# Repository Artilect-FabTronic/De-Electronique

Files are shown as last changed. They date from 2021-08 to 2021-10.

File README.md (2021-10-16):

# Projet de dé électronique

L'ambition de ce projet, est de vous permettre de vous initier à la conception d'une carte électronique à travers un exemple simple, que vous concevrez vous même.
Une fois que vous s'aurez dessiner et réaliser un premier circuit imprimer (PCB), vous pourrez réaliser vos propres montages électroniques.

## Description

On se propose de réaliser le dé électronique d'Heliox, qui lorsqu'on le secoue, tire un numéro de 1 à 6 de manière aléatoire.

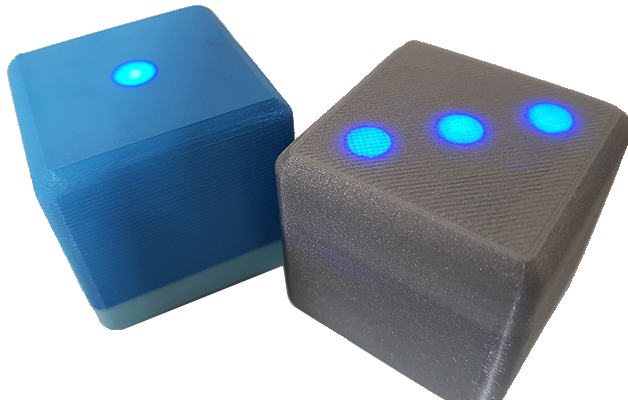
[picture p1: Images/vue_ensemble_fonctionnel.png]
Dé réalisé par Heliox


L'objectif est d'avoir un système minimaliste afin de pouvoir le faire fonctionner à partir d'une pile bouton de 3V.

Nous utiliserons donc un microcontrôleur ATtiny85 du fabricant Microchip, compatible avec les cartes Arduino ([ATtiny microcontroller comparison chart](https://en.wikipedia.org/wiki/ATtiny_microcontroller_comparison_chart)).

Voici deux sources du projet, parmi d'autres que vous retrouverez sur Internet.

1. <http://carrefour-numerique.cite-sciences.fr/wiki/doku.php?id=projets:de_electronique>

2. Le tutoriel d'Heliox est articulé en 4 épisodes :
    1. 📺 [Fabrication d'un circuit imprimé avec transfert de toner](https://youtu.be/8joLK039fjk)
    2. 📺 [Explication rapide du circuit imprimé et comment placer les composants dessus](https://youtu.be/6BOH1eVT2Hk)
    3. 📺 [Programmation du microcontrôleur ATtiny85 pour faire fonctionner le dé](https://youtu.be/S-oBujsoe-Q), [Code source HelioxLab](https://github.com/HelioxLab/electronicdice)
    4. 📺 [Création et modélisation de l'objet 3D final](https://youtu.be/o8AYCznNaCQ)

<!-- Routage du PCB réalisé par Heliox avec le logiciel  <https://fritzing.org/download/> -->
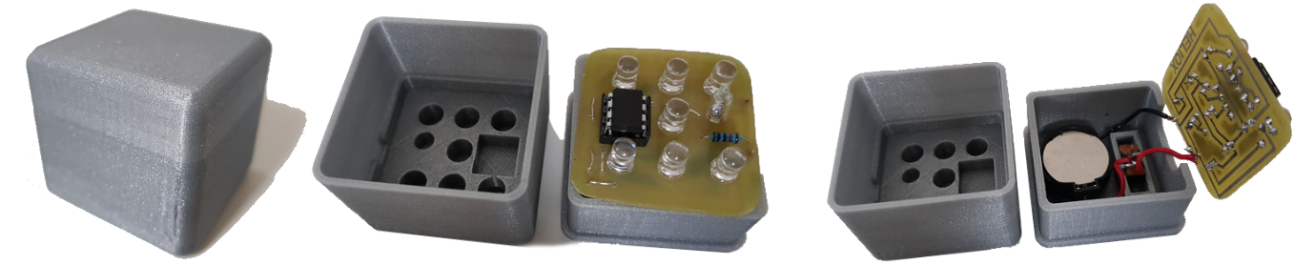
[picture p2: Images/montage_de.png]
montage du de conçu par Heliox


## Evolution possible du projet

- Projet initial à partir du tutoriel d'Heliox et des composants traversants
- Même projet mais avec une carte électronique supportant des composants CMS
- Autre version avec l'utilisation de [registre à décalage](https://fr.wikipedia.org/wiki/Registre_%C3%A0_d%C3%A9calage) pour le pilotage des LED
- [Projet plus ambitieux avec des LED sur toutes les faces](https://www.youtube.com/watch?v=6NPTslF68Q0&ab_channel=maker.moekoe)

## Les outils logiciels utilisés

- CAO éléctronique KiCad en version 5.99 "[Nightly Development Builds](https://www.kicad.org/download/windows/)", est téléchargeable depuis la page du serveur, aller tout en bas pour trouver la dernière date de compilation :
<https://kicad-downloads.s3.cern.ch/index.html?prefix=windows/nightly/>
- CAO mécanique [FreeCAD](https://www.freecadweb.org/?lang=fr)
- [Arduino IDE 1.8.15](https://www.arduino.cc/en/software)
- [Visual Studio Code](https://code.visualstudio.com/)

## Le matériel du projet dé électronique (BOM)

- Matériaux PLA pour l'imprimante 3D, à partir des [fichiers STL fournis par HELIOX](https://www.thingiverse.com/thing:2798081)
- Un fer à souder pour assembler les composants sur le circuit imprimé (PCB), ainsi qu'un petit outillage, comme un multimètre, des pinces, etc...
- [Interrupteur à bascule 3 broches 1P2T, poignée haute 4 mm, SS12F15](https://fr.aliexpress.com/item/32765155281.html)
- [Piles bouton au Lithium 3V, CR2032](https://fr.aliexpress.com/item/1005001314447472.html)
- [ATtiny85](https://www.microchip.com/wwwproducts/en/ATtiny85), [Microcontrôleur MCU 8BIT 20MHZ, 8 broches DIP-8 ATTINY85](https://fr.aliexpress.com/item/32952262601.html), [ATTINY85V-10PU](https://octopart.com/attiny85v-10pu-microchip-77762335), [Farnell 1455165](https://fr.farnell.com/microchip/attiny85v-10pu/mcu-8bit-attiny-10mhz-dip-8/dp/1455165) (l'option V permet de descendre la tension d'alimentation jusqu'à 1V8)
- Interrupteur à bille (mouvement et inclinaison) : [Capteur de vibrations en métal, Boule d'inclinaison secouant commutateur, SW-520D SW520D](https://www.aliexpress.com/item/100PCS-SW-520D-SW520D-Vibration-Sensor-Metal-Ball-Tilt-Shaking-Switch/4000680935322.html)
- [Kit de LED, taille 5 mm, 2V ou 3 V, ensemble d'ampoules couleurs chaudes, blanc, rouge, bleu, vert, orange, jaune](https://fr.aliexpress.com/item/1936218827.html)
- [Assortiment de condensateurs électrolytiques, 125 Pieces 1uF 2200uF 25 Valeurs](https://www.amazon.fr/gp/product/B00JZETYIG/ref=ppx_yo_dt_b_asin_title_o01_s00)
- [Boîtier/Socket support DIP 8 broches, 0.3 inch / 7.62mm](https://www.amazon.fr/gp/product/B016S6ZQQM/ref=ppx_yo_dt_b_asin_title_o00_s00)
- [Kit résistance à fil métallique, 600 pcs/lot, 30 valeurs* 20 pcs de 10 ohms ~ 1 M ohm, 1 %, 1/4 W](https://fr.aliexpress.com/item/1005001774876666.html)
- [Support de piles, CR2032, pour piles bouton 3V](https://fr.aliexpress.com/item/32845557622.html),  modèle 3D : [20mm THT Coin Cell Holder](https://grabcad.com/library/20mm-tht-coin-cell-holder-1)

---

## Schématique

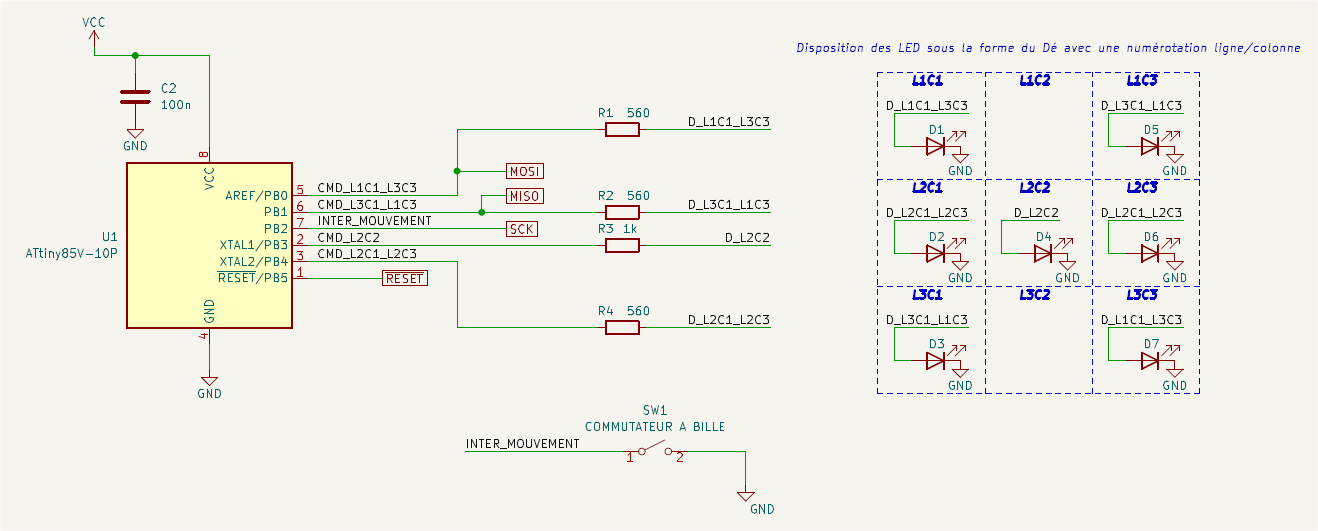
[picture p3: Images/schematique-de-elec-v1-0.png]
schematique-de-elec-v1-0


"arduino attiny85 pinout" depuis la page : https://learn.sparkfun.com/tutorials/tiny-avr-programmer-hookup-guide/attiny85-use-hints

Brochage (Pinout en Anglais) de l'ATtiny85 :

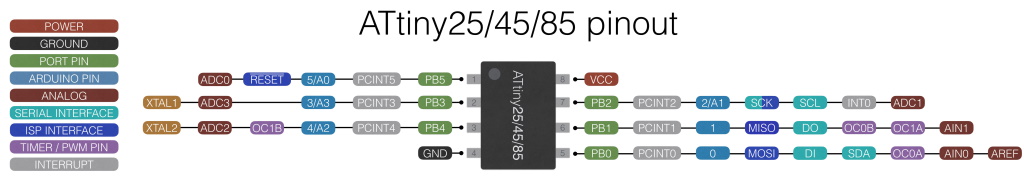
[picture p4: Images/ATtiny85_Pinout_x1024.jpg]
ATtiny85 Pinout


[Programmation de l’ATtiny85](http://makerspace56.org/transformer-une-arduino-uno-en-programmateur-isp-dattiny-par-exemple/)

Afin de pouvoir programmer l'ATtiny85, nous utiliserons un connecteur dit **_ISP_** ou **_ICSP_** pour In-circuit Serial Programmer, de 2x3 broches, voir [Arduino as ISP and Arduino Bootloaders](https://www.arduino.cc/en/pmwiki.php?n=Tutorial/ArduinoISP).

Nous pouvons nous inspirer du schéma d'implantation du connecteur de programmation ICSP à partir du schéma de la [carte Arduino Nano](https://store.arduino.cc/arduino-nano).

Et pour la programmation, suivre les instruction ici : [Programming ATtiny85 with Arduino Uno](https://create.arduino.cc/projecthub/arjun/programming-attiny85-with-arduino-uno-afb829)

Si vous avez tous suivi, vous aurez vu que par défaut, l'environnement Arduino IDE ne prend pas en charge les microcontrôleurs ATtiny85. Nous devons donc ajouter les cartes ATtiny à l'IDE Arduino.

Pour cela, ouvrez le menu "Fichier -> Préférences" et dans les URL du gestionnaire de cartes supplémentaires, ajoutez cette URL :

`https://raw.githubusercontent.com/damellis/attiny/ide-1.6.x-boards-manager/package_damellis_attiny_index.json`

Puis ajouter le support pour les [ATtiny](https://github.com/damellis/attiny) depuis le gestionnaire de carte.

Une fois cela effectué, vous pourrez choisir le type de carte ATtiny25/45/85, préciser bien le modèle du "processeur" ATtiny85 et le choix de l'horloge interne à 8 MHz.

TODO: passer à 1 MHz et voir la différence de consommation...

## Carte électronique

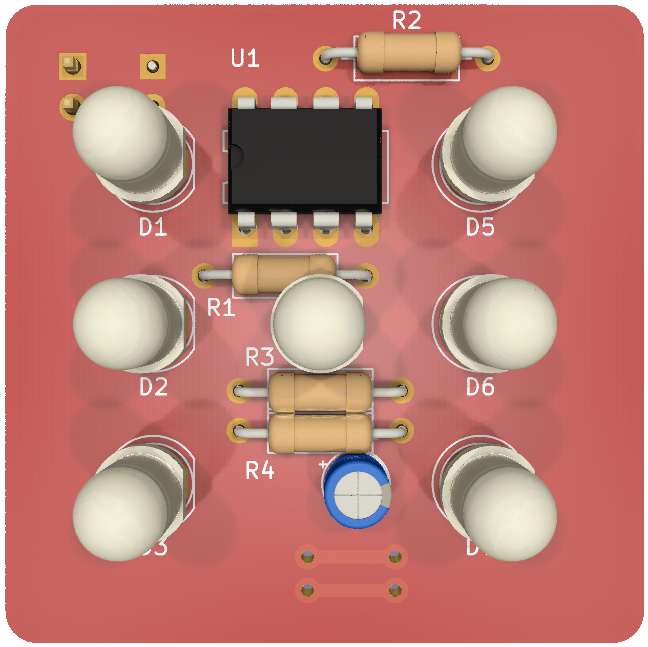
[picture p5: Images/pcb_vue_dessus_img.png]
carte-de-elec-v1-0-vue-dessus
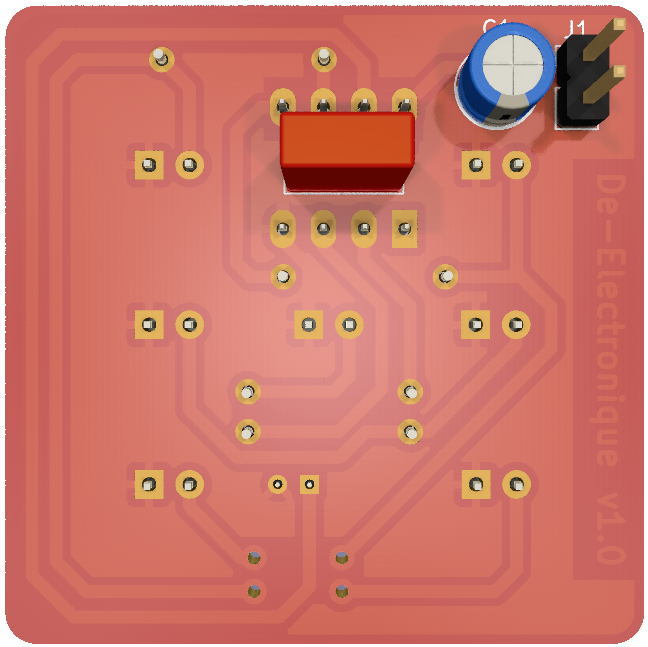
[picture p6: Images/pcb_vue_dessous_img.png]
carte-de-elec-v1-0-vue-dessous


### Programmation de l'ATtiny85 depuis une carte Arduino Uno

Une fois le programme compilé sous l'IDE Arduino (version 1.8.16 sous Windows 10, avec les paramètres de carte : "ATtiny25/45/85, ATtiny85, Internal 8 MHz"), il est important pour la programmation de votre ATtiny85 cible de bien configurer le programmer externe, afin de pouvoir effectuer la programmation.

---

### Description du fonctionnement

Nous allons étudier ensemble le montage électronique ;-)

Le microcontrôleur ATtiny85 dispose de 8 broches, dont 2 sont réservées pour son alimentation électrique.

Nous devons donc sélectionner les broches numériques d'entrées/sorties (E/S) permettant le bon fonctionnement de notre projet.

Tout d'abord, nous aurons besoin d'une entrée pour le capteur de mouvement à bille.
Il faut alors ce pencher sur les fonctions des broches du microcontrôleur afin de pouvoir décider quelle broche nous sera utile afin de pouvoir détecter cet évènement.

Mettre les LED sous la forme du dé avec une numérotation Ligne/Colonne (L/C) :

| L/C  |  C1  |  C2  |  C3  |
|:---:|:----:|:----:|:----:|
| **L1** | L1C1 | L1C2 | L1C3 |
| **L2** | L2C1 | L2C2 | L2C3 |
| **L3** | L3C1 | L3C2 | L3C3 |

- Chiffre 1 : (L2C2)
- Chiffre 2 : (L3C1 + L1C3)
- Chiffre 3 : (L3C1 + L1C3) + (L2C2)
- Chiffre 4 : (L3C1 + L1C3) + (L1C1 + L3C3)
- Chiffre 5 : (L3C1 + L1C3) + (L1C1 + L3C3) + (L2C2)
- Chiffre 6 : (L3C1 + L1C3) + (L1C1 + L3C3) + (L2C1 + L2C3)

En regroupant les LED entre parenthèse, nous voyant que nous devons piloter séparément les groupes suivant, si l'on veux pouvoir afficher tous les chiffres :

- 1 broche en sortie pour commander la LED L2C2, nous la nommerons CMD_L2C2
- 1 broche en sortie pour commander les LED L3C1 et L1C3, nous la nommerons CMD_L3C1L1C3
- 1 broche en sortie pour commander les LED L1C1 et L3C3, nous la nommerons CMD_L1C1L3C3
- 1 broche en sortie pour commander les LED L2C1 et L2C3, nous la nommerons CMD_L2C1C3

Soit un total de 4 broches en sorties pour la commande des LED du projet :

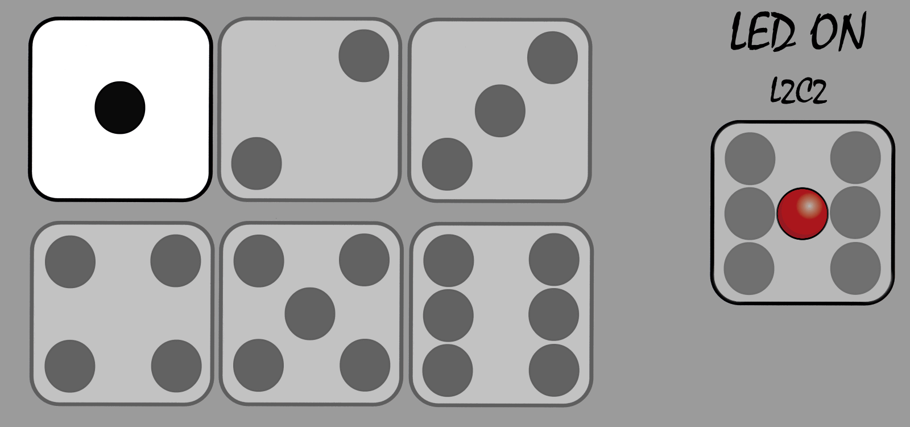
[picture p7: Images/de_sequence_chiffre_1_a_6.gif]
Pilotage des LED


Consommation en veille = 373 uA
Consommation au repos = 800 uA
Consommation avec 1 LED = 2.62 mA
Consommation avec 4 LED = 8.13 mA

---

## Internet ⚀, ⚁, ⚂, ⚃, ⚄, ⚅

- [Dé — Wikipédia](https://fr.wikipedia.org/wiki/D%C3%A9)
- [Lancez un dé virtuel!](https://de.virtuworld.net/)
- [Patrons de dés à jouer](https://www.fiche-maternelle.com/fabriquer-son-des-a-jouer.html)
- [Fabriquer soit même un Dé électronique sans Arduino](https://www.youtube.com/watch?v=spbdDq6kvxw&ab_channel=ElectroMic)
- [dé électronique qui se déclenche par passage de la main au dessus d'une photorésistance](https://sciences-du-numerique.fr/projet-arduino-pour-la-specialite-isn/de-electronique/41)

---

## License

MIT License Projet Open Hardware et Open Source by Artilect (https://opensource.org/licenses/MIT)

[Open Hardware](https://fr.wikipedia.org/wiki/Mat%C3%A9riel_libre)

[MIT License](https://opensource.org/licenses/MIT)

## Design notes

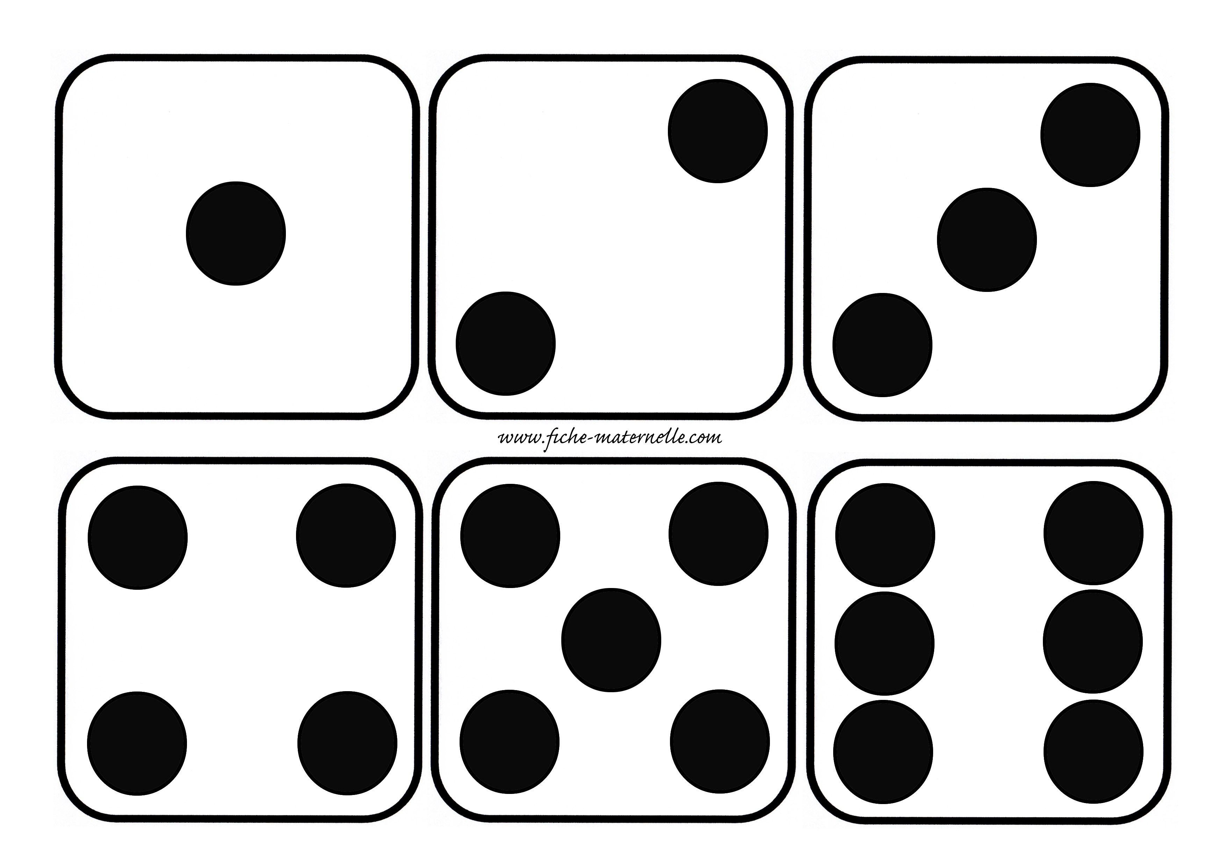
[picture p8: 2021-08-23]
Images/les_faces_du_de.jpg

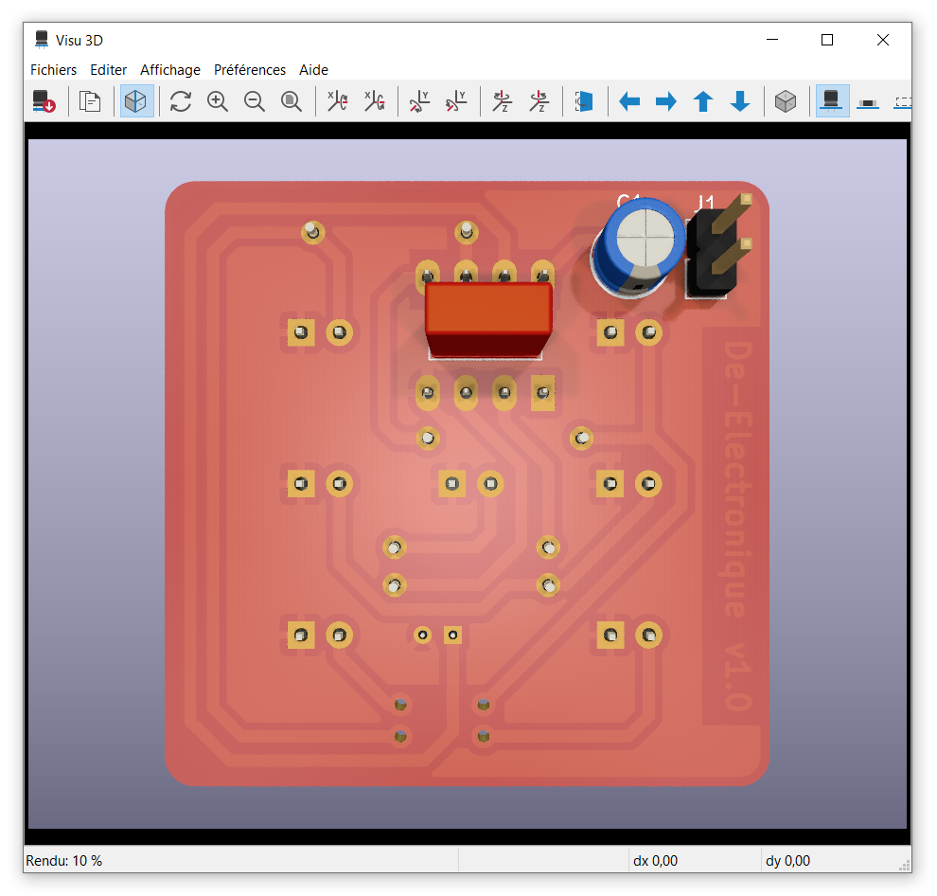
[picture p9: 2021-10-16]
Images/pcb_vue_dessous.png

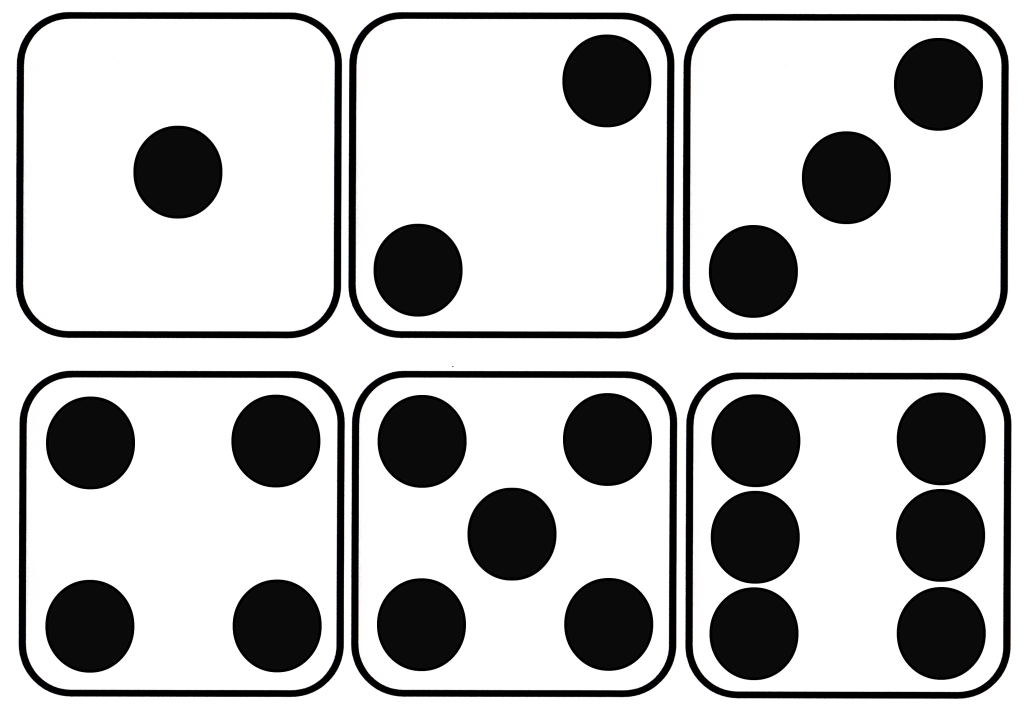
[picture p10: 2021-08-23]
Images/les_faces_du_de.png

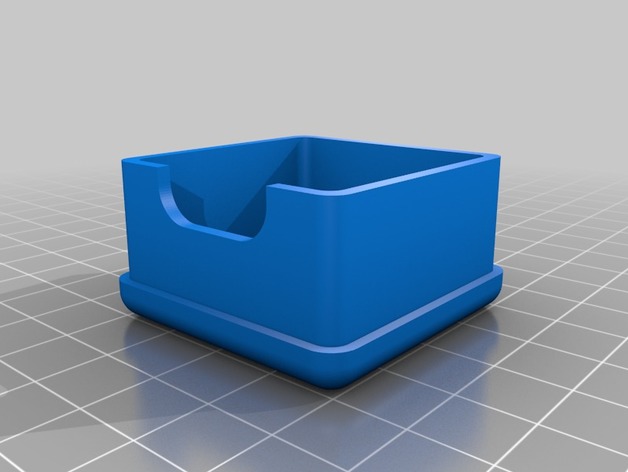
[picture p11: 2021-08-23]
Images/vue_dessous.jpg

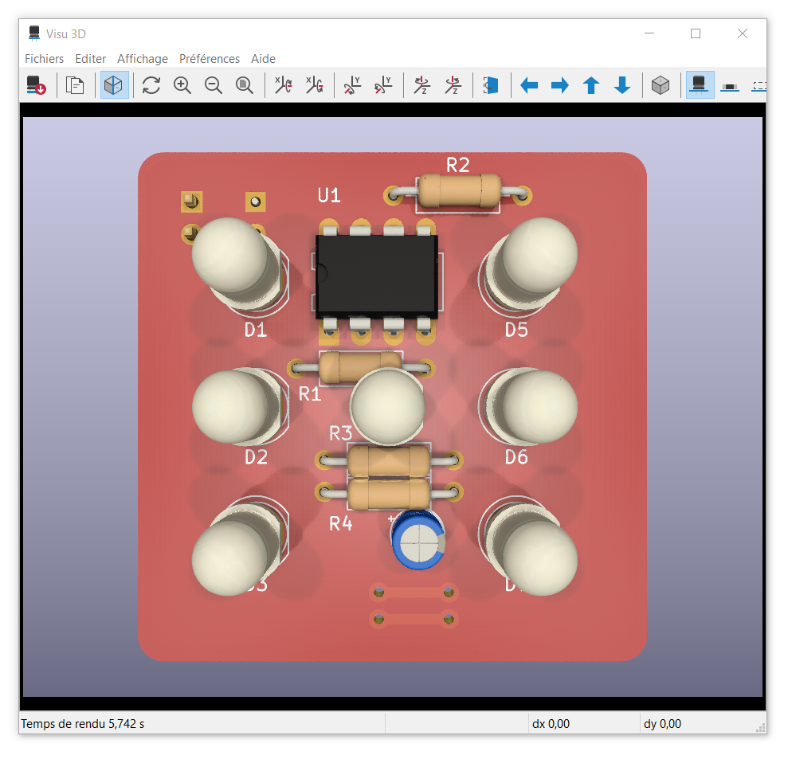
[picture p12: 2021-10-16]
Images/pcb_vue_dessus.png

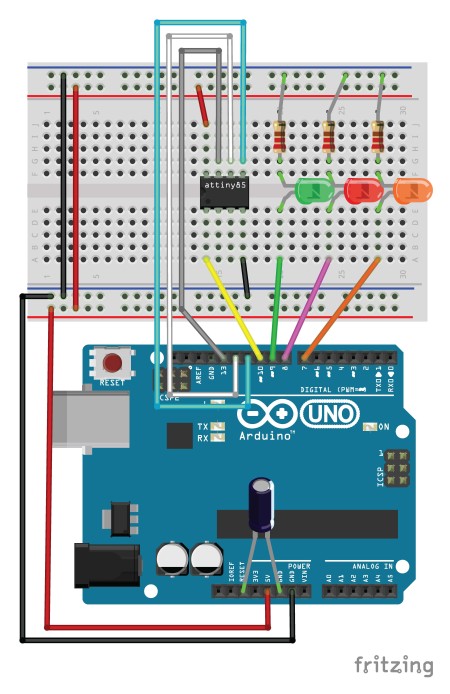
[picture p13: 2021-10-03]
Images/Programmation-AtTiny85-ArduinoUno-ISP.jpg

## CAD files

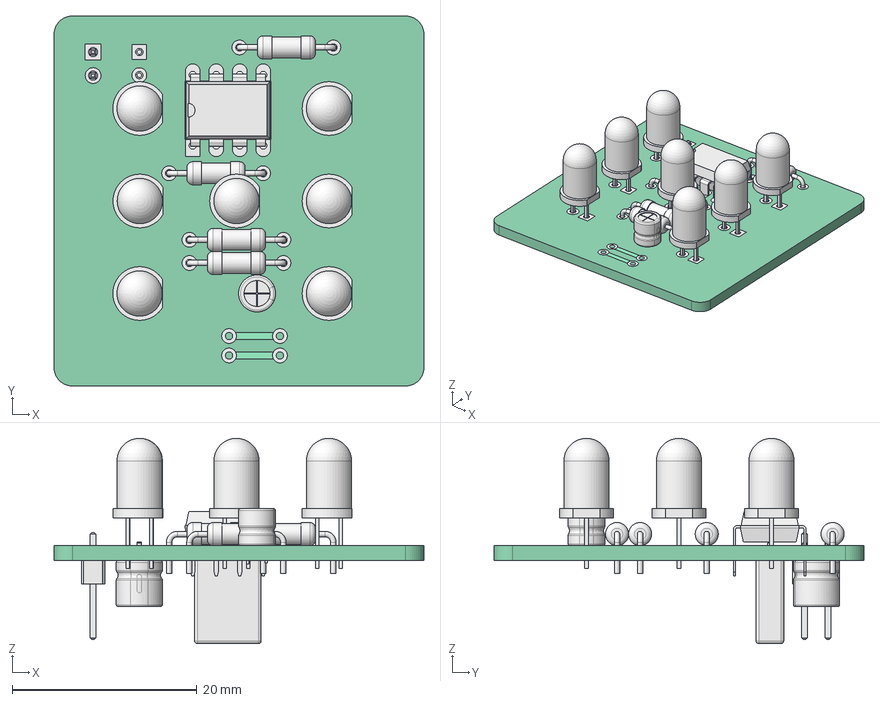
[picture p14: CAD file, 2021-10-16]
CAO-3D/PCB-De-Elec-THT.FCStd
40.0 x 40.0 x 22.2 mm
Pcb_6ee0
topPads_6ee0
topTracks_6ee0
botPads_6ee0
botTracks_6ee0
botZones_6ee0
D3_LED_D5.0mm_Clear_c8d51a1c0c0e x 7
U1_DIP-8_W7.62mm_69495754b2d9
R3_R_Axial_DIN0207_L63mm_D25mm_P1016mm_Horizontal_48222e3e548a x 4
SW1_CP_Radial_D40mm_P200mm_0d74ae5376be
C2_C_Rect_L72mm_W30mm_P500mm_FKS2_FKP2_MKS2_MKP2_9a8d65592bbd
J1_PinHeader_1x02_P254mm_Vertical_77a5e3965d3b
C1_CP_Radial_D50mm_P250mm_6f870ca8c2a1

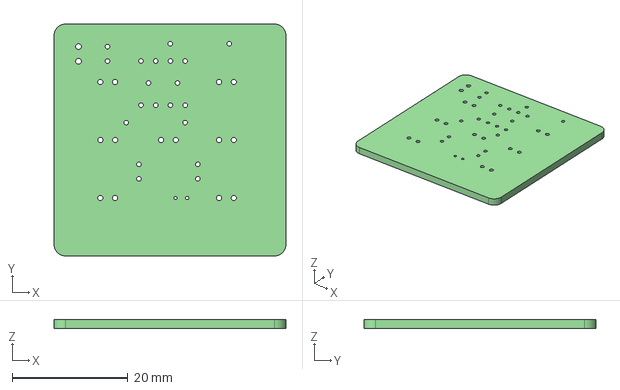
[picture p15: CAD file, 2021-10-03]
CAO-Kicad/CAO-Kicad.step
40.0 x 40.0 x 1.60 mm

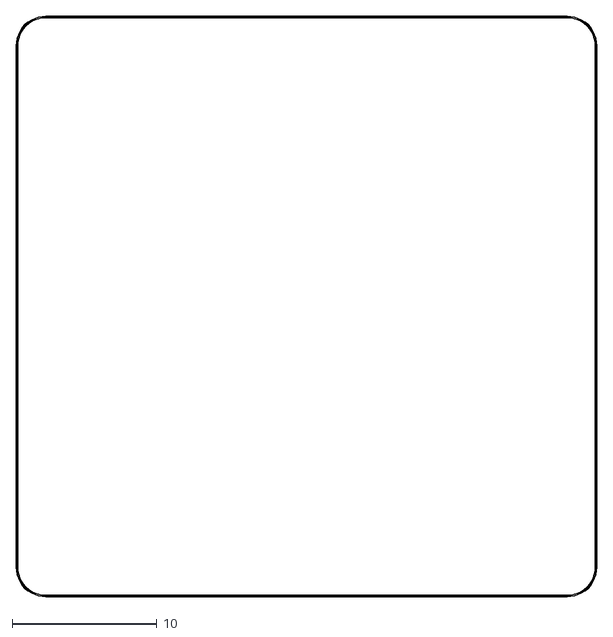
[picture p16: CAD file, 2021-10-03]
CAO-Kicad/GERBER/CAO-Kicad-Edge_Cuts.dxf
40.1 x 40.1

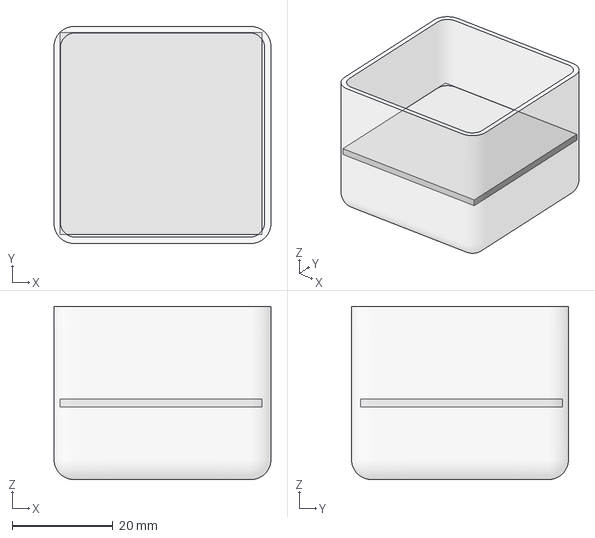
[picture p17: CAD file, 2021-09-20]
CAO-3D/Top-To-PCB.FCStd
43.0 x 43.0 x 34.3 mm
PCB
Top

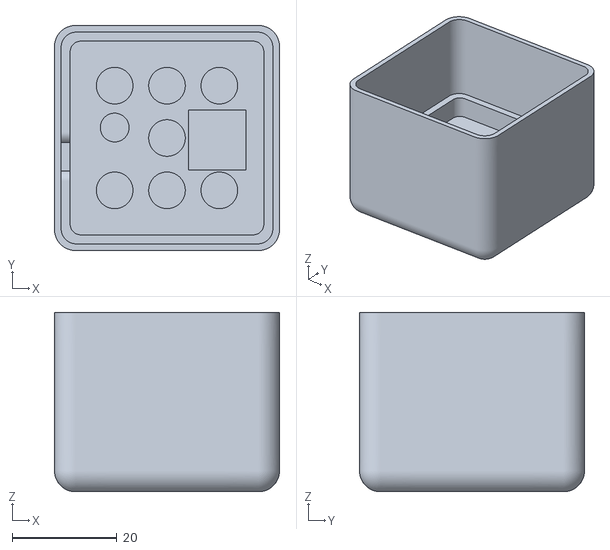
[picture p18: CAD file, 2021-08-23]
CAO-3D/Top.stl
43.0 x 43.0 x 34.3

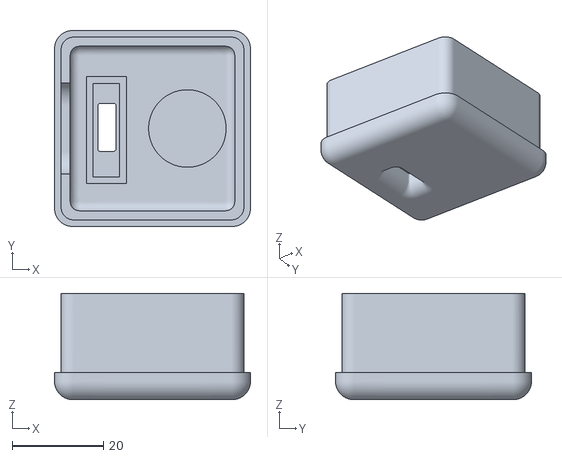
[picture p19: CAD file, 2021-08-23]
CAO-3D/Bottom.stl
43.0 x 43.0 x 23.3

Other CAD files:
CAO-Kicad/GERBER/CAO-Kicad-B_Silkscreen.dxf
CAO-Kicad/GERBER/CAO-Kicad-F_Silkscreen.dxf

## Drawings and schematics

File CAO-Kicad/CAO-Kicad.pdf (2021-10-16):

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

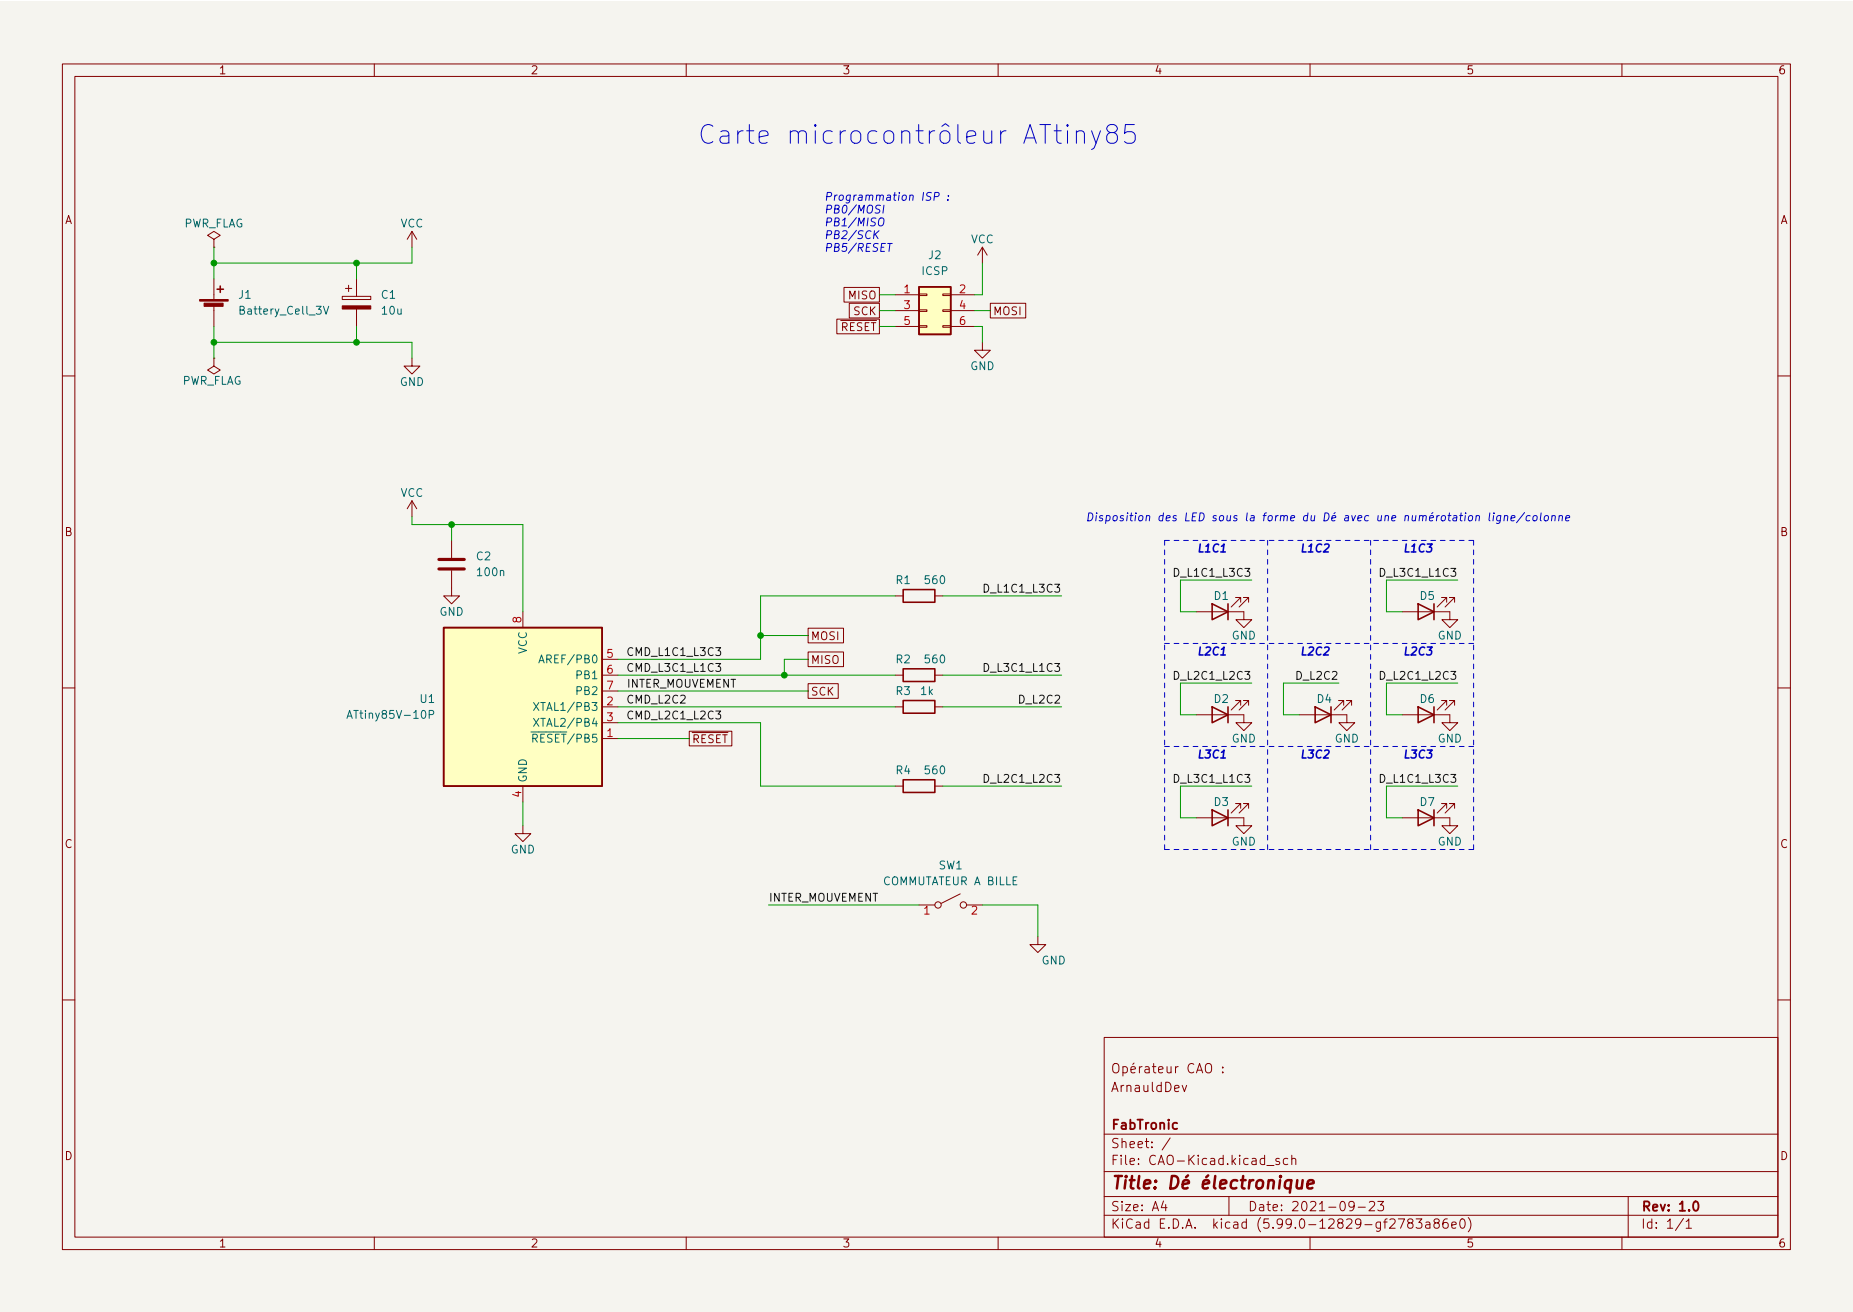
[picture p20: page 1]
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

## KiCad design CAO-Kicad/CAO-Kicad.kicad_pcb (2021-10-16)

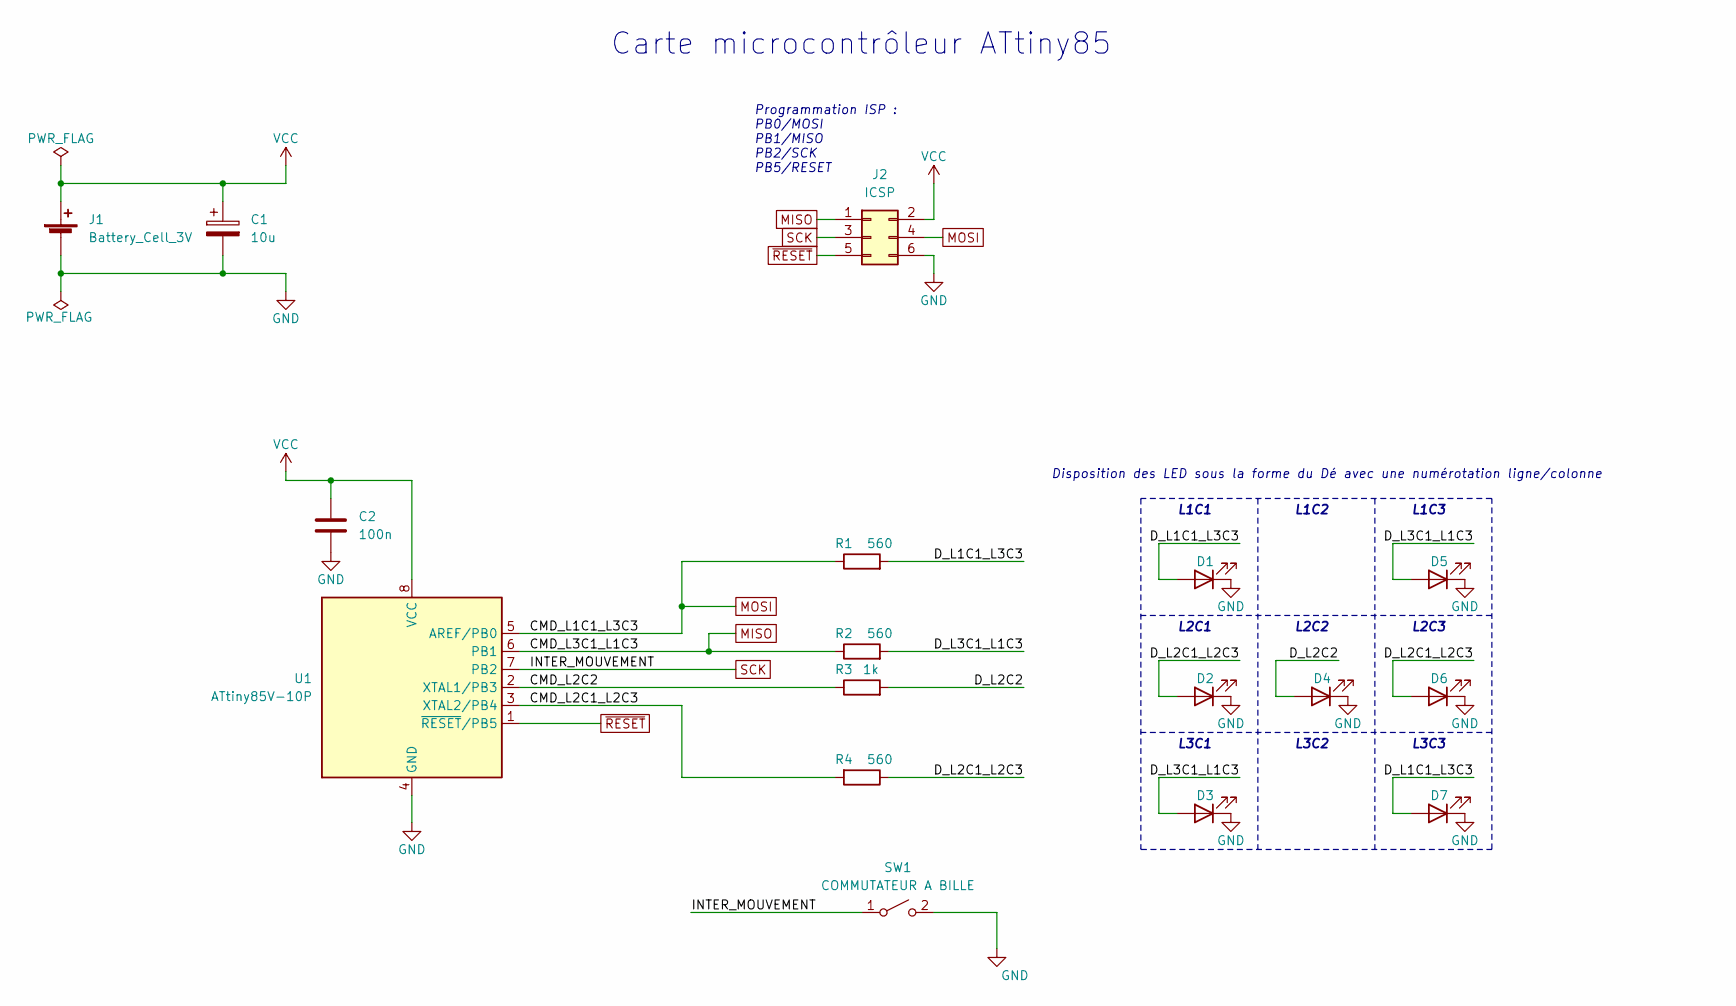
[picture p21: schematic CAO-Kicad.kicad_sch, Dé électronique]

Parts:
C1: 10u; CP_Radial_D5.0mm_P2.50mm
C2: 100n; C_Rect_L7.2mm_W3.0mm_P5.00mm_FKS2_FKP2_MKS2_MKP2
D1, D2, D3, D4, D5, D6, D7: LED; LED_D5.0mm_Clear
J1: Battery_Cell_3V; PinHeader_1x02_P2.54mm_Vertical
J2: ICSP; PinHeader_2x03_P2.54mm_Vertical
R1, R2, R4: 560; R_Axial_DIN0207_L6.3mm_D2.5mm_P10.16mm_Horizontal
R3: 1k; R_Axial_DIN0207_L6.3mm_D2.5mm_P10.16mm_Horizontal
SW1: COMMUTATEUR A BILLE; CP_Radial_D4.0mm_P2.00mm
U1: ATtiny85V-10P; DIP-8_W7.62mm_LongPads

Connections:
/CMD_L2C1_L2C3: R4.2, U1.3 (XTAL2/PB4)
/CMD_L2C2: R3.1, U1.2 (XTAL1/PB3)
/D_L1C1_L3C3: D1.2 (A), D7.2 (A), R1.2
/D_L2C1_L2C3: D2.2 (A), D6.2 (A), R4.1
/D_L2C2: D4.2 (A), R3.2
/D_L3C1_L1C3: D3.2 (A), D5.2 (A), R2.2
GND: C1.2, C2.2, D1.1 (K), D2.1 (K), D3.1 (K), D4.1 (K), D5.1 (K), D6.1 (K), D7.1 (K), J1.2 (-), J2.6, SW1.2 (B), U1.4 (GND)
MISO: J2.1, R2.1, U1.6 (PB1)
MOSI: J2.4, R1.1, U1.5 (AREF/PB0)
SCK: J2.3, SW1.1 (A), U1.7 (PB2)
VCC: C1.1, C2.1, J1.1 (+), J2.2, U1.8 (VCC)
~RESET: J2.5, U1.1 (~RESET/PB5)

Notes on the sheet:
Carte microcontrôleur ATtiny85
Programmation ISP : PB0/MOSI PB1/MISO PB2/SCK PB5/RESET
Disposition des LED sous la forme du Dé avec une numérotation ligne/colonne
L1C1
L2C1
L3C1
L1C2
L2C2
L3C2
L1C3
L2C3
L3C3

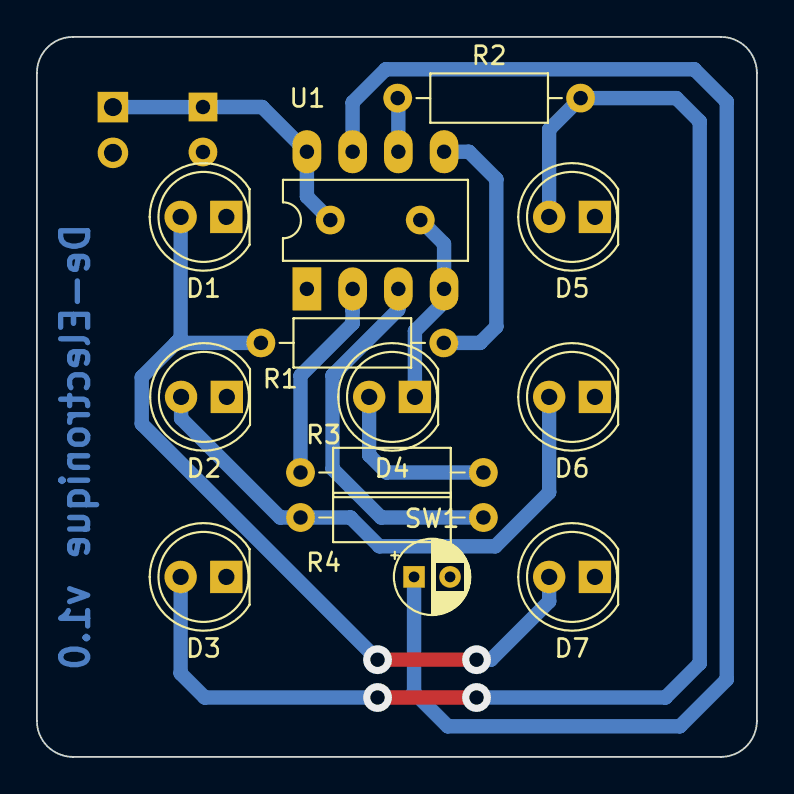
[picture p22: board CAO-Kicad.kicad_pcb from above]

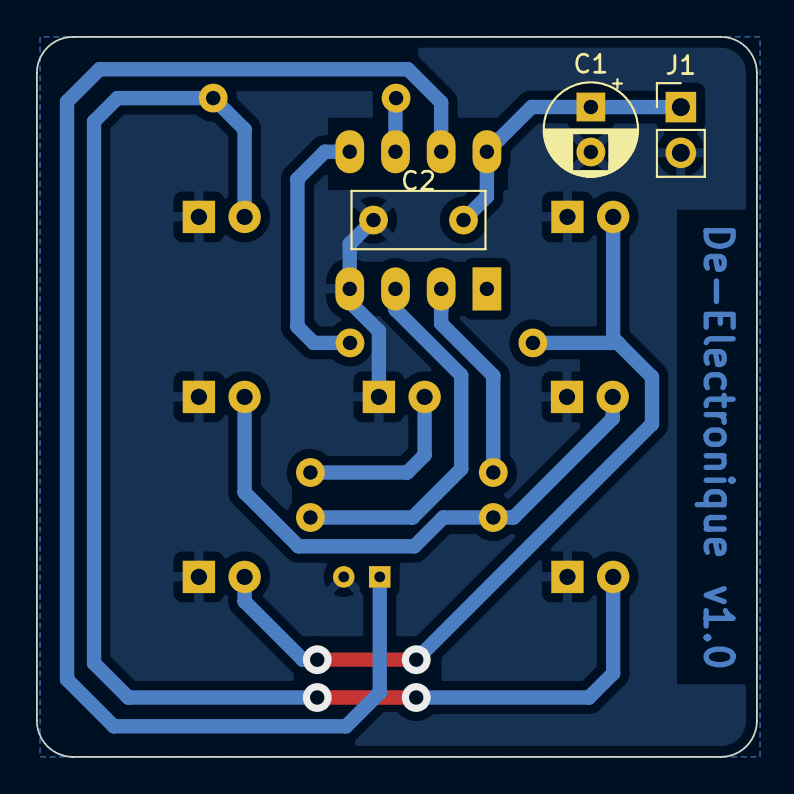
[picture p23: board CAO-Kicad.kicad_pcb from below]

Board: 2 copper layers, 40.0 x 40.0 mm, 16 parts (3 on the bottom side), 11 nets.

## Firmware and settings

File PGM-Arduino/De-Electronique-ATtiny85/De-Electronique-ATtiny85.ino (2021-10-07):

/**
   Projet du dé électronique - FabTronic 2021
   Source : 
   
   ATtiny85 (8MHz)

   Libraries used are the properties of the respective authors.

   Sleep mode use about 70 µA (0.07 mA)

   Battery life in sleep mode, assuming 10 wake-ups pr.hour:
   ----------------------------------------------------------
   2 x AA at 2500mAh      =
   1 x 3.7v Saft LS14500  =
   1 x 550mAh coin cell   =
   1 x 240mAh coin cell   =
   ----------------------------------------------------------
   Battery Life Calculator <http://oregonembedded.com/batterycalc.htm>

   Reference > Language > Functions > Random numbers > Random
   https://www.arduino.cc/reference/en/language/functions/random-numbers/random/

*/


// ATMEL ATTINY 25/45/85 / ARDUINO
//
//                  +--\/--+
// Ain0 (D 5) PB5  1|      |8  Vcc
// Ain3 (D 3) PB3  2|      |7  PB2 (D 2) Ain1 / INT0
// Ain2 (D 4) PB4  3|      |6  PB1 (D 1) pwm1
//            GND  4|      |5  PB0 (D 0) pwm0
//                  +------+

#include <avr/io.h>
#include <avr/interrupt.h>
//#define F_CPU 8000000ul
#include <util/delay.h>
#include <avr/sleep.h>

#define adc_disable() (ADCSRA &= ~(1<<ADEN)) // disable ADC (before power-off)

//#warning "F CPU = "
//#warning F_CPU

/*
Correspondance des E/S avec <http://carrefour-numerique.cite-sciences.fr/wiki/doku.php?id=projets:de_electronique>
PB0 = CMD_L1C1L3C3 // Leds 1 et 6
PB1 = CMD_L3C1L1C3 // Leds 2 et 5
PB2 = SW1, COMMUTATEUR A BILLE
PB3 = CMD_L2C2 // Led 7
PB4 = CMD_L2C1C3 // Leds 3 et 4
*/
#define LEDUNSIX       0     // Leds 1 et 6 sur PB1
#define LEDTROISQUATRE 4     // Leds 3 et 4 sur PB5
#define LEDDEUXCINQ    1     // Leds 2 et 5 sur PB4
#define LEDSEPT        3     // Leds 7 sur PB3

#define UNESECONDE     100   // 1 seconde égal à 1000 ms --> TODO: Déterminer la Fq de travail et la bonne valeur

volatile uint8_t roll = 0, initSeed = 0, seed = 0;

ISR(INT0_vect) {
  MCUCR &= ~(1 << SE); // Idle of sleep mode -> disable
  roll = 1;
  if (initSeed == 0) {
    randomSeed(seed);
    initSeed = 1;
  }
}

void action() {
  uint8_t tirage = 0;
  uint8_t newTirage = 0;

  //  for (uint8_t i = 0; i < random(10, 21); i++) {
  for (uint8_t i = 0; i < random(3, 11); i++) {
    do {
      newTirage = random(1, 7);
    } while (tirage == newTirage);
    tirage = newTirage;

    onEteind();
    afficheTirage(tirage); // on affiche le tirage
    _delay_ms(UNESECONDE / 4);
  }

  // Phase de tirage réel
  onEteind();
  do {
    newTirage = random(1, 7);
  } while (tirage == newTirage);

  afficheTirage(newTirage);
  _delay_ms(UNESECONDE * 5);  // Tirage final, on fait une pause de 5 secondes
  onEteind();
  roll = 0;
}

void init_ISR() { // INITIALISATION des routines d'initialisation
  PORTB |= 1 << PB2;   // configuration du bit 0 du port B avec résistance de PULL UP (PB2)
  MCUCR |= 1 << ISC01; // Falling EDGE INT0 (PB2)
  GIMSK |= 1 << INT0;  // Activate the INT0
  sei();               // Active General Interrupt
}

void init_GPIO() {
  // On configure les PINs en sortie pour les LEDs
  DDRB |= (1 << LEDUNSIX) | (1 << LEDTROISQUATRE) | (1 << LEDDEUXCINQ) | (1 << LEDSEPT);
}

void onEteind() {
  PORTB &= ~((1 << LEDUNSIX) | (1 << LEDTROISQUATRE) | (1 << LEDDEUXCINQ) | (1 << LEDSEPT));
  _delay_ms(UNESECONDE / 5);
}

void afficheTirage(uint8_t tirage) {
  PORTB &= ~((1 << LEDUNSIX) | (1 << LEDTROISQUATRE) | (1 << LEDDEUXCINQ) | (1 << LEDSEPT));
  switch (tirage) {
    case 1:
      PORTB |= (1 << LEDSEPT);
      break;
    case 2:
      PORTB |= (1 << LEDUNSIX);
      break;
    case 3:
      PORTB |= (1 << LEDUNSIX) | (1 << LEDSEPT);
      break;
    case 4:
      PORTB |= (1 << LEDUNSIX) | (1 << LEDDEUXCINQ);
      break;
    case 5:
      PORTB |= (1 << LEDUNSIX) | (1 << LEDDEUXCINQ) | (1 << LEDSEPT);
      break;
    case 6:
      PORTB |= (1 << LEDUNSIX) | (1 << LEDDEUXCINQ) | (1 << LEDTROISQUATRE);
      break;

    default:
      // if nothing else matches, do the default
      // default is optional
      break;
  }
}

int main() {
  init_GPIO();
  init_ISR();
  adc_disable();

  while (1) {
    if (initSeed == 0) {
      seed++;
    }

    if (roll == 1) {
      action();
      MCUCR |= (1 << SE); // Idle Mode of sleep mode
      sleep_mode();
    }
  }

  return 0;
}

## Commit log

2021-07-26 ajout projet Kicad
    [CAO-Kicad.kicad_pcb, CAO-Kicad.kicad_sch]
2021-07-29 Ajout du conn ICSP et du contour de carte 100x100mm
    [CAO-Kicad.kicad_pcb, CAO-Kicad.kicad_sch, de_elec.kicad_sch]
2021-08-10 Ajout de la serigraphie et recherche composants
    [CAO-Kicad.kicad_pcb, CAO-Kicad.kicad_sch, de_elec.kicad_sch]
2021-08-23 Ajout des docs et images
    [Bottom.stl, CAO-Kicad.kicad_pcb, CAO-Kicad.kicad_sch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]
2021-08-23 Importation des composants vers le circuit imprimé
    [CAO-Kicad.kicad_pcb, CAO-Kicad.kicad_sch, de_elec.kicad_sch]
2021-09-20 MAJ pour la realiser un PCB de 40x40 mm
    [CAO-Kicad-User_1.dxf, CAO-Kicad.kicad_pcb, CAO-Kicad.kicad_sch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]
2021-09-20 Routage de la carte electronique
    [CAO-Kicad.kicad_pcb, CAO-Kicad.kicad_sch]
2021-10-03 MAJ nommenclature
    [CAO-Kicad-Edge_Cuts.dxf, CAO-Kicad-User_1.dxf, CAO-Kicad.kicad_pcb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]
2021-10-07 mod the prog file. Disabled the ADC
2021-10-16 Mise à jour du fichier README
    [CAO-Kicad-B_Silkscreen.dxf, CAO-Kicad-F_Silkscreen.dxf, CAO-Kicad.kicad_pcb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]
